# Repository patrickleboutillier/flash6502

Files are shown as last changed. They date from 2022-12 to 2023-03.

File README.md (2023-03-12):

# flash6502
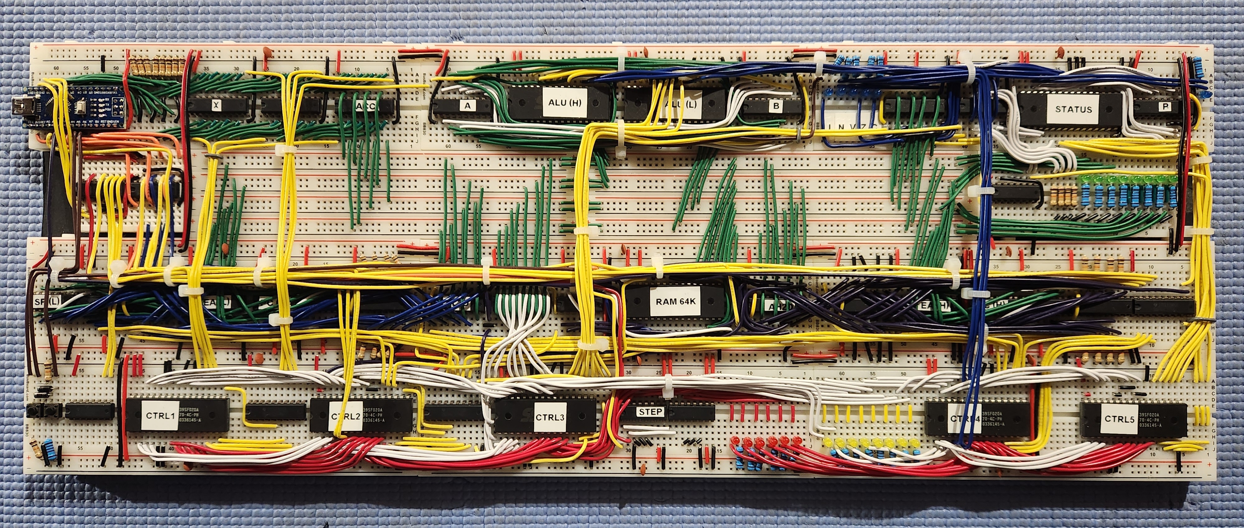
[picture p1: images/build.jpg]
Build


Trying to build a 6502-compatible CPU on breadboards, using as few chips as possible.

## Introduction
For a while I've been working on small projects that implement various "toy/fictitious" CPUs (namely the [Scott CPU](https://github.com/patrickleboutillier/jcscpu-hmc)) using discrete components, but I grew frustrated for 2 reasons:

1. Memory space is usually to small to create useful/fun programs.
2. You have to write your own assembler and tool chain.

After viewing Ben Eater's great video series on the 6502, I wondered if it might be possible to implement a 6502 CPU (not *a computer using a 6502 CPU chip*...) on breadboards using discrete components. Also, since breadboard projects tend to take up a lot of space very quickly (in squares inches I mean), I decided to try and use the least amount of chips possible, ideally under 40.

## Architecture

### Architecture Decisions
In order to achieve these goals, I made the following architecture decisions:

- It's ok if it's slower (perhaps even some orders of magnitude slower) than a real 6502.
- It's ok for the design to be assisted by a microcontroller (i.e. Arduino) for power, clocking and for some complicated parts like the reset sequence.
- It's ok if it doesn't run actual existing 6502 ROMs, but it has to run programs that I write myself using a standard 6502 assembler.
- It's ok if the actual 6502 timing is not respected.
- It's ok to use chips that did not exist at the time the 6502 was designed, namely large ROMs (which are used extensively), in order to keep the chips count low and simplify the design.

### High-Level Architecture
The system is made up of 8 sections, which I will refer to using the following names:

- **Registers**: contains the Arduino controller, as well as the X, Y and ACC registers.
- **ALU**: contains the 8-bit ALU with 16 operations, as well as the A and B registers that are connected to it.
- **Status**: contains the status (P) register, as well as the status logic implementd in a ROM chip. There is also a multiplexer to select the source for the status bits (ALU or data bus) and a buffer to control sending the status byte to the data bus.
- **Data Bus**: the 8 bit data bus.
- **Address Low**: contains the low bytes of the stack pointer (SP), the program counter (PC) and the effective address (EA) register, all connected to the "address low" bus, as well as a buffer to allow sourcing any of these from the data bus.
- **Address High**: contains the high bytes of the stack pointer (SP), the program counter (PC) and the effective address (EA) register, all connected to the "address low" bus, as well as a buffer to allow sourcing any of these (except the high byte of SP which is a constant) from the data bus.
- **RAM**: contains the instruction register (INST), the 64k RAM chip (connected to the "address low" and "address high" busses, as well as the data bus) and the memory mapping logic, as well as 2 buffers allowing to send the contents of the "address low/high" buses to the data bus.
- **Control Unit**: contains the stepping logic and 5 ROM chips that handle the 40 control signals. Each ROM chip receives the output of the step counting (6 bits), the output of the INST register (8 bits), as well as 4 other input signals that vary depending on the chip.

### Breadboard Block Diagram
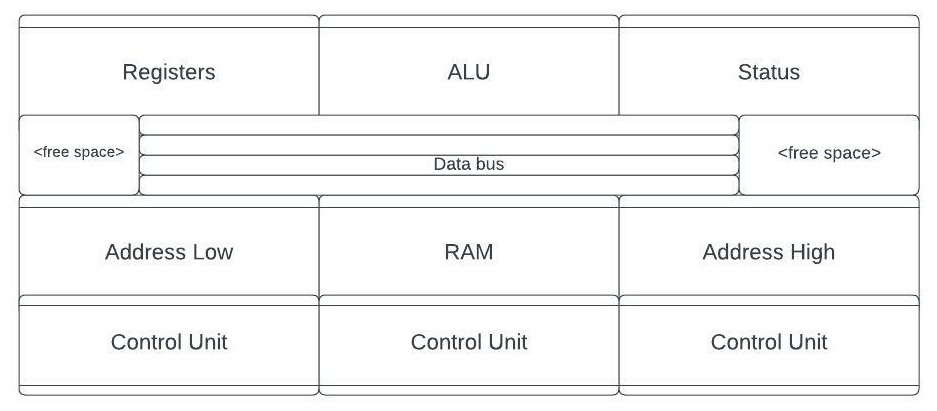
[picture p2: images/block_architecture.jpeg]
Block Diagram


## Sections
### Registers
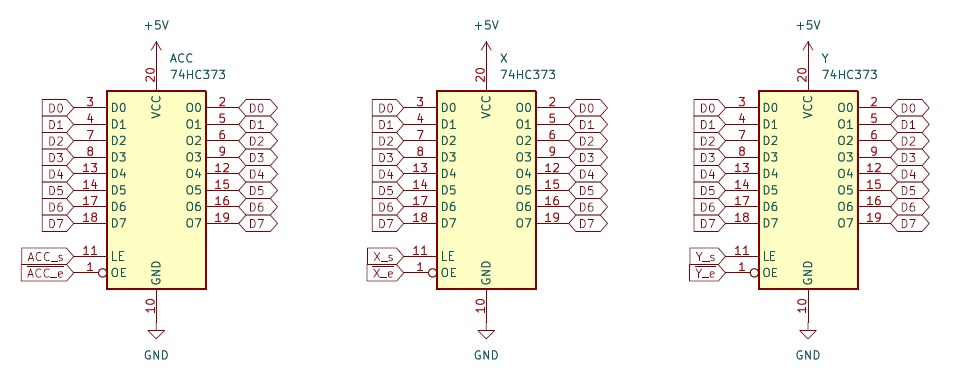
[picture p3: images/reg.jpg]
Registers


The Registers section contains 3 registers, ACC, X and Y, implemented using SN74HC373 chips. These registers are connected to the Data Bus. There are 6 control signals used to set or enable each of these 3 registers: *ACC_e*, *ACC_s*, *X_e*, *X_s*, *Y_e*, *Y_s*.

### ALU
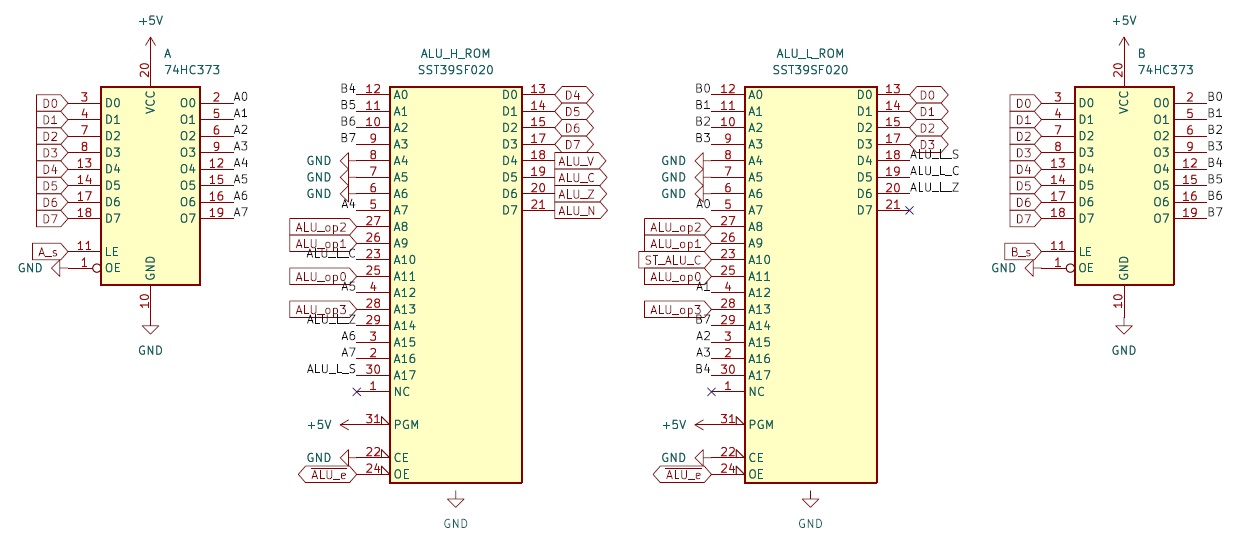
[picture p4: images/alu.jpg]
ALU


The ALU section contains 2 registers, A and B, implemented using SN74HC373 chips. These registers can be set from the Data Bus, and their outputs are fed directly into the ALU. The ALU is made up of 2 SST39SF020A Flash chips. It has 15 operations that can be selected using 4 controls bits.
The operations are defined as such:

    #define ALU_ADC  0    // For ADC instruction
    #define ALU_AND  1    // For AND instruction
    #define ALU_BIT  2    // For BIT instruction
    #define ALU_CMP  3    // For CMP instruction
    #define ALU_DEC  4    // For DEC instruction
    #define ALU_EOR  5    // For EOR instruction
    #define ALU_INC  6    // For ADC instruction
    #define ALU_LSR  7    // For LSR instruction
    #define ALU_ORA  8    // For ORA instruction
    #define ALU_ROL  9    // For ROL instruction
    #define ALU_ROR  10   // For ROR instruction
    #define ALU_SBC  11   // For SBC instruction
    #define ALU_PASS 12   // Passes through the contents of the B register
    #define ALU_ADD  13   // ADD w/o carry. Used mostly in address calculations
    #define ALU_SXT  14   // Sign extention, used in relative address calculation

Here are the details of each of the pins for the 2 Flash chips, ALU Low and ALU High:
#### ALU Low
- A16, A15, A12, A7: The low nibble of the A register.
- A3, A2, A1, A0: The low nibble of the B register.
- A13, A8, A9, A11: The ALU operation (see above).
- A10: The "ALU carry" output of the Status section.
- A17: Bit 4 of the B register. Used, for example, during the "shift right" operations.
- A14: Bit 7 of the B register. Used during the "sign extend" operation. 
- DQ3, DQ2, DQ1, DQ0: The low nibble of the result of the operation (these pins are connected to the Data Bus).
- DQ6: The "zero" output of the operation.
- DQ5: The "carry" output of the operation.
- DQ4: The "shift" output of the operation.
- OE#: Connected to the *ALU_e* control signal used to enable the result onto the Data Bus.

#### ALU High
- A16, A15, A12, A7: The high nibble of the A register.
- A3, A2, A1, A0: The high nibble of the B register.
- A13, A8, A9, A11: The ALU operation (see above).
- A10: The "carry" output from ALU Low.
- A17: The "shift" output fron ALU Low.
- A14: The "zero" output fron ALU Low.
- DQ3, DQ2, DQ1, DQ0: The high nobble of the result of the operation (these pins are connected to the Data Bus).
- DQ7: The N output flag of the ALU.
- DQ6: The Z output flag of the ALU.
- DQ5: The C output flag of the ALU.
- DQ4: The V output flag of the ALU.
- OE#: Connected to the *ALU_e* control signal used to enable the result onto the Data Bus.

#### Control signals
The control signals for the ALU section are *ALU[3-0]*, *ALU_e*, *A_s* and *B_s*.

### Status
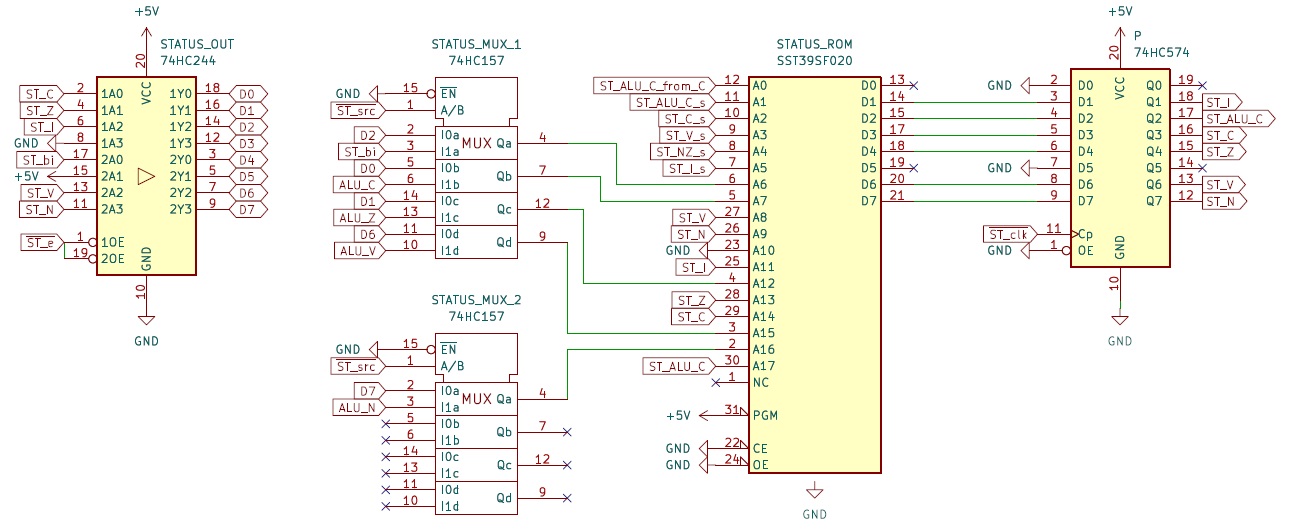
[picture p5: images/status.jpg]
Status

The Status section is made up of the P register, which stores the current values for the Status flags, as well a custom flag (ALU_C) to store the carry used for the ALU carry-in signal, which may be different from the Status carry (C) flag.

The Status ROM is the brains of the Status module. It receives as input:
- The outputs of the P register (the "current" Status flag values)
- The "new" Status flag inputs, that come either from the ALU or from the Data Bus
  - 2 SN74HC157 MUX chips are used to feed these inputs to the Status ROM 
- Control signals that indicate which Status flags are to be set

Finally the Status module also contains a SN74HC244 chip that controls the sending of the Status flags to the Data Bus when required.

#### Control signals
The control signals for the Status section are *ST_e*, *ST_bi*, *ST_src*, *ST_NZ_s*, *ST_C_s*, *ST_V_s*, *ST_I_s*, *ST_ALU_C_s*, *ST_ALU_C_from_C*.

### Data Bus
The Data Bus is really just a combination of 4 breadboard power rails, along with some LEDs to help with debugging.
### Address Low
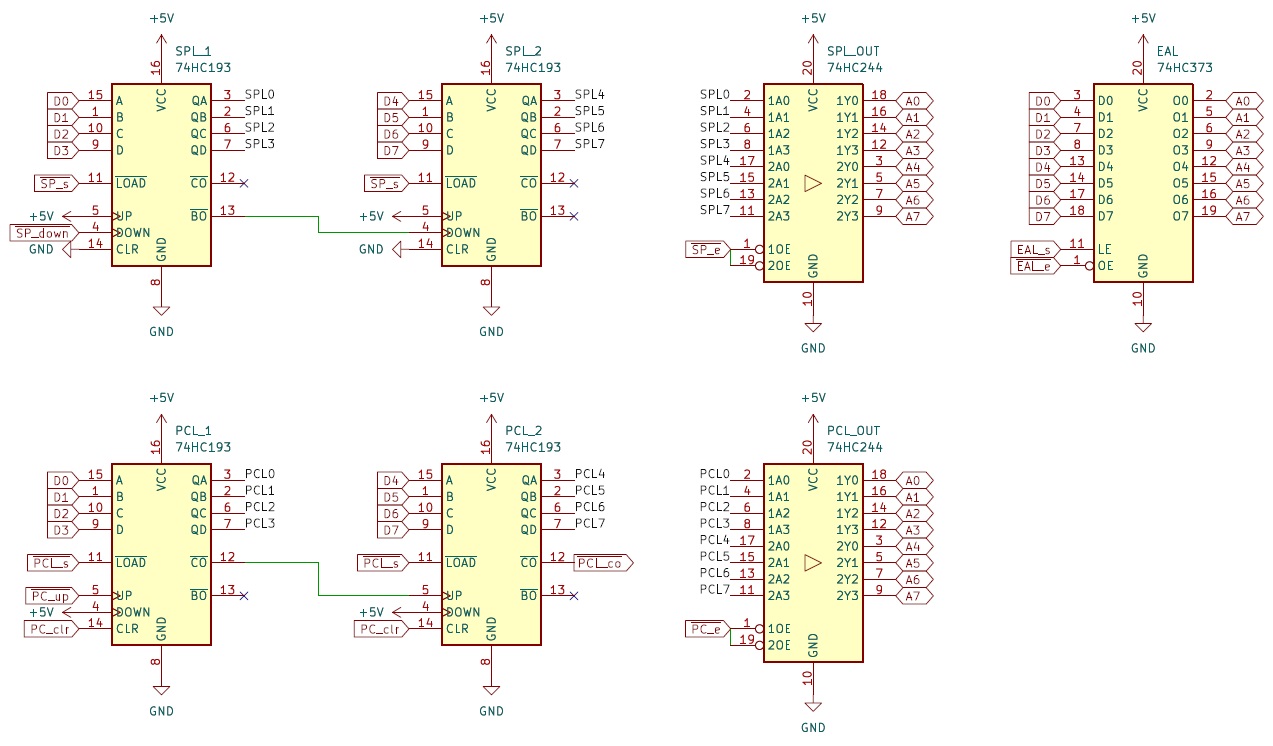
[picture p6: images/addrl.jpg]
Address Low

TODO: Description
### Address High
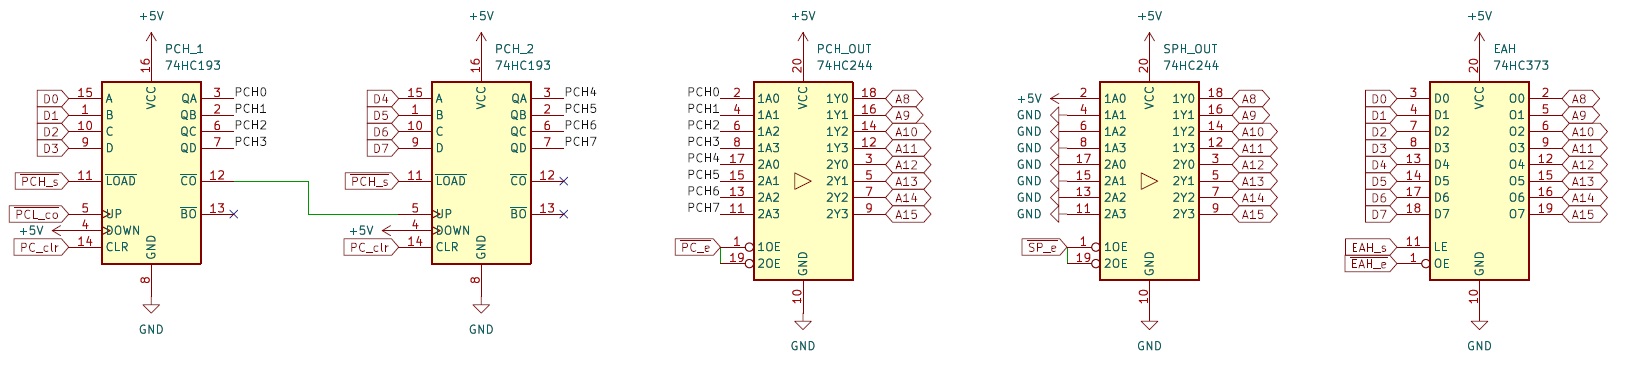
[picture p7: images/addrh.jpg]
Address High

TODO: Description
### RAM
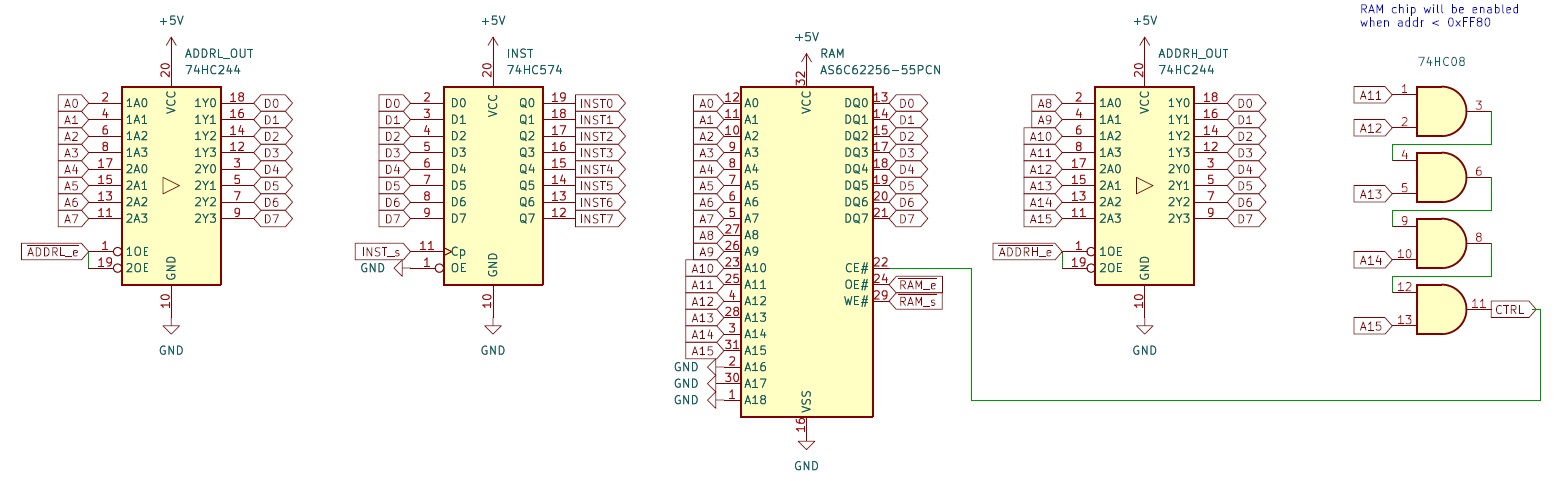
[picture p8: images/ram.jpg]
RAM

TODO: Description
### Control Unit
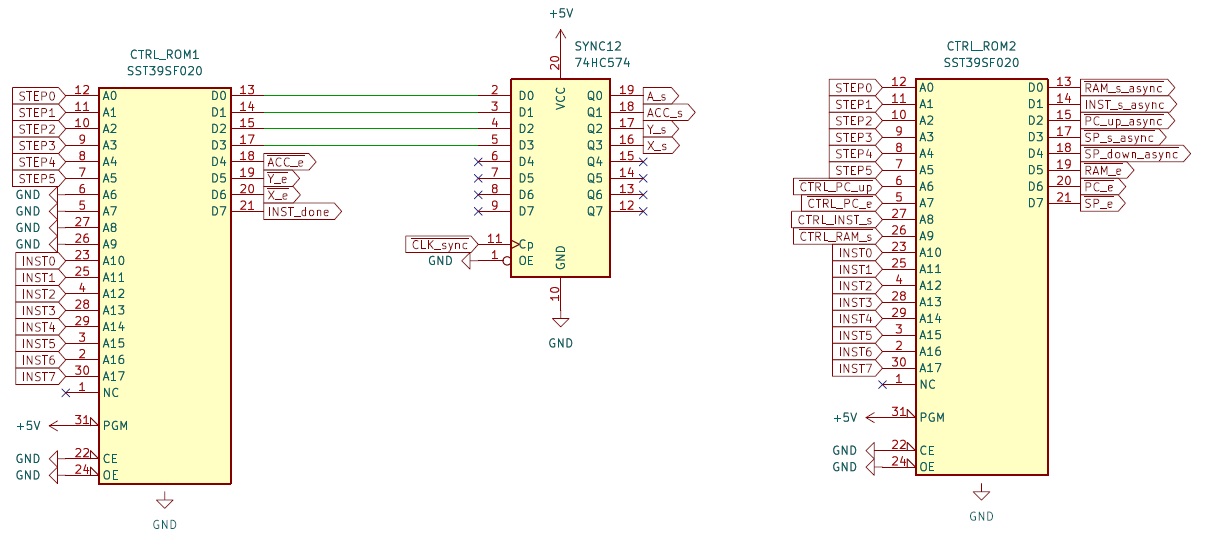
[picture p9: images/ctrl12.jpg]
CU12

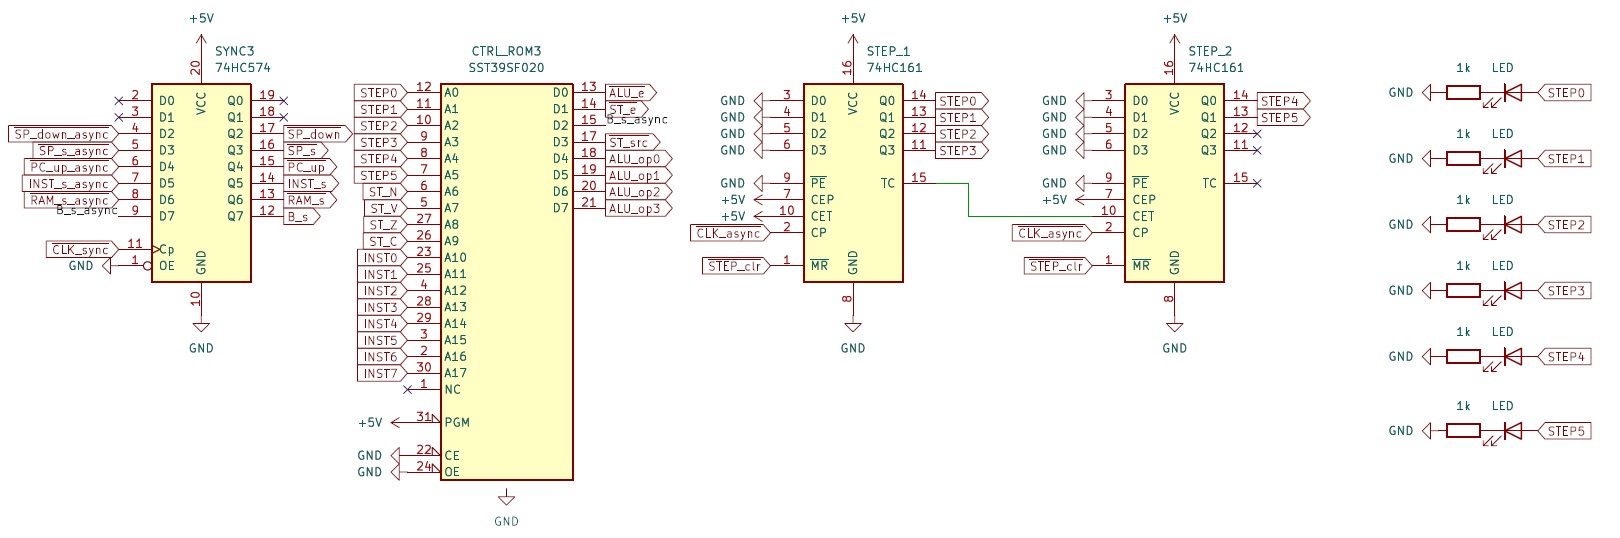
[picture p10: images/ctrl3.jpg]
CU3

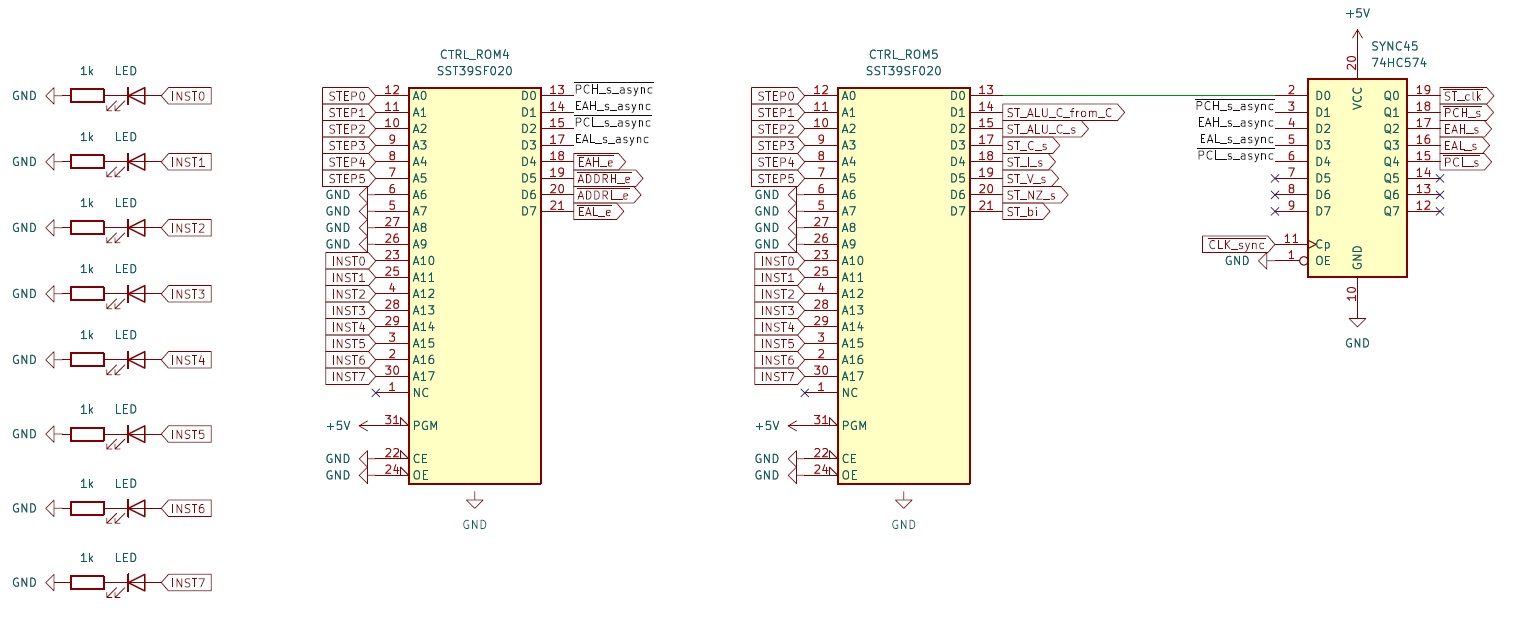
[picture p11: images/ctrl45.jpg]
CU45

TODO: Description
### Arduino Controller
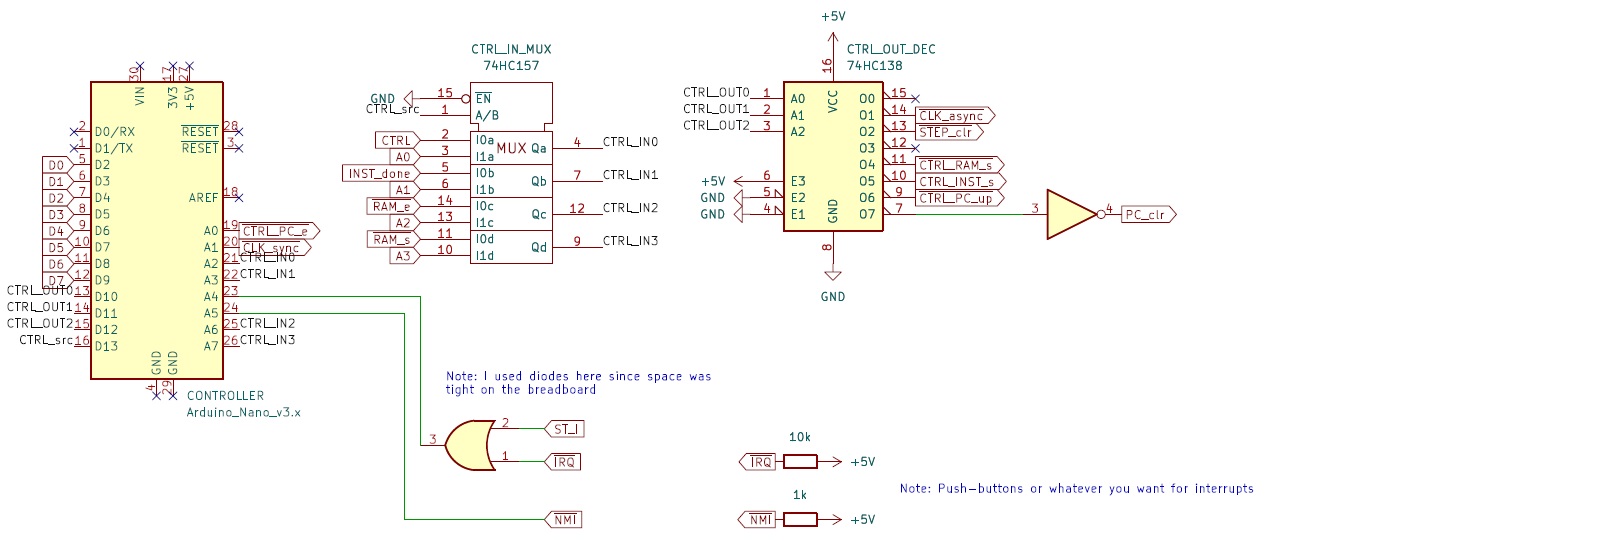
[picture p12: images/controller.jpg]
Controller

TODO: Description

## Schematic
You can find the complete KiCAD Schematic here: [KiCAD Schematic](./docs/kicad/flash6502/)

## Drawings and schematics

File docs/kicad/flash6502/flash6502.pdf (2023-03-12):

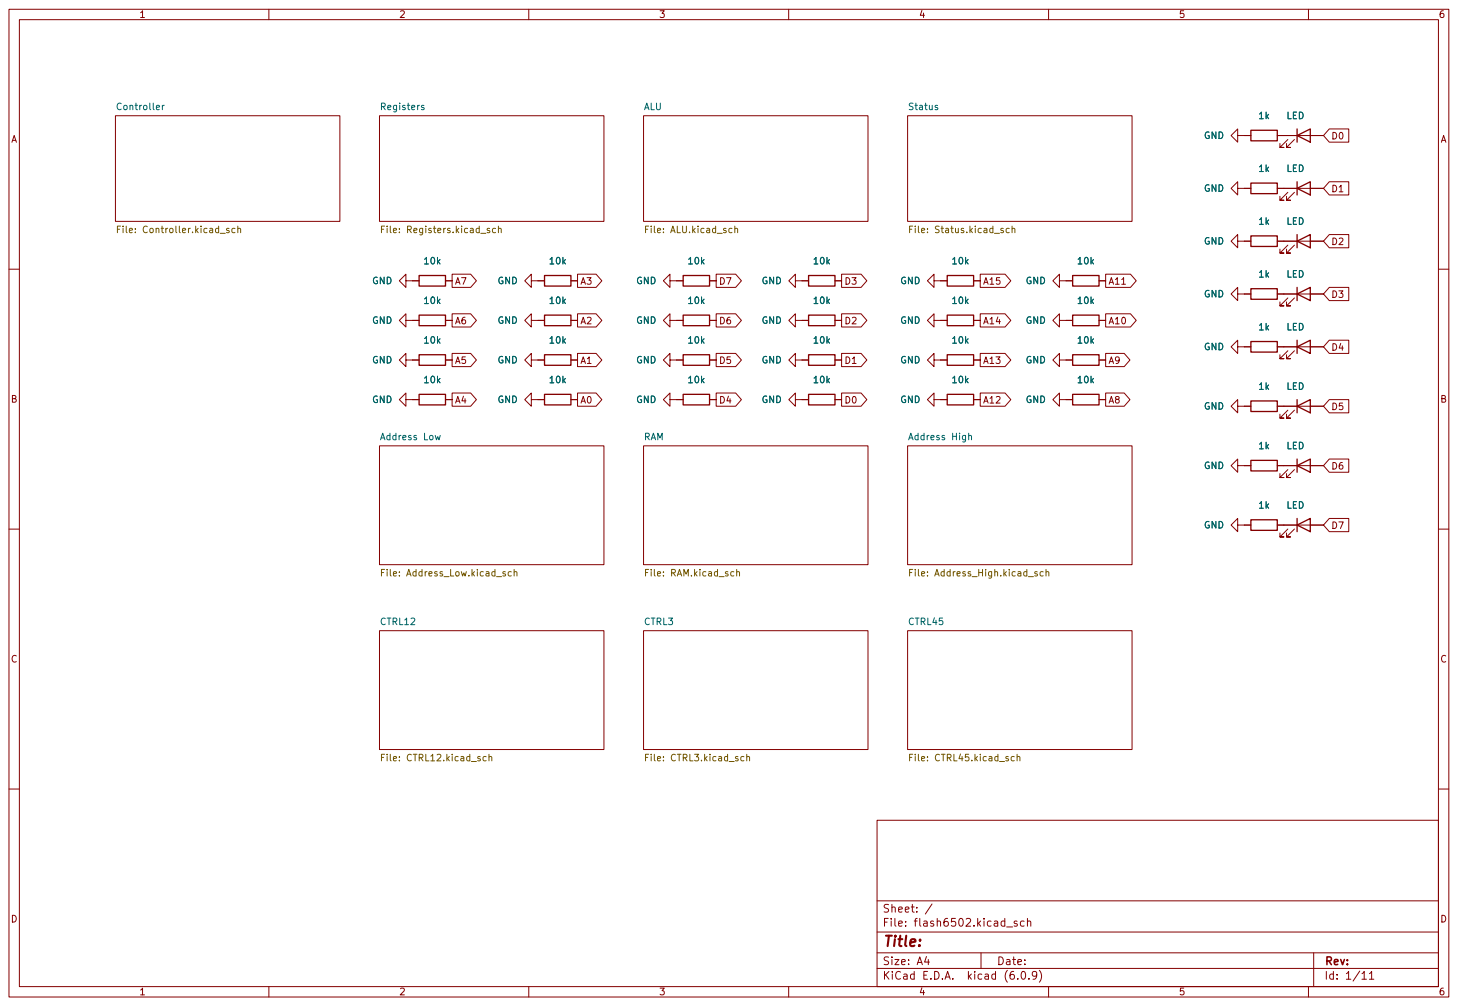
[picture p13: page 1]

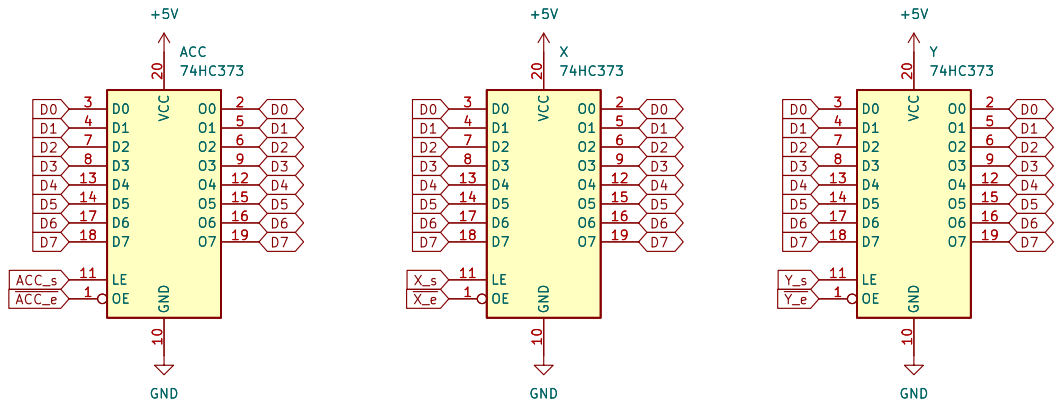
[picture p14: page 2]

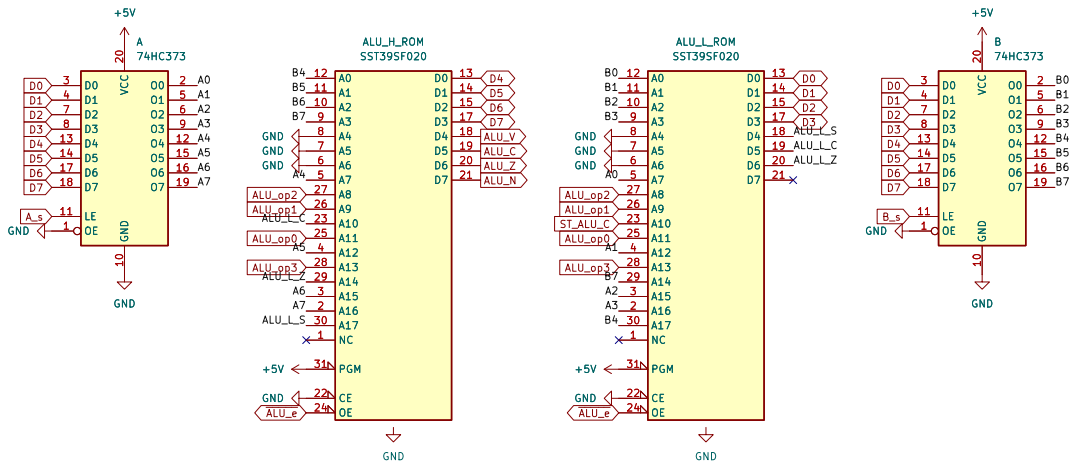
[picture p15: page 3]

File: ALU.kicad_sch Sheet: /ALU/
Id: 3/11 Title:

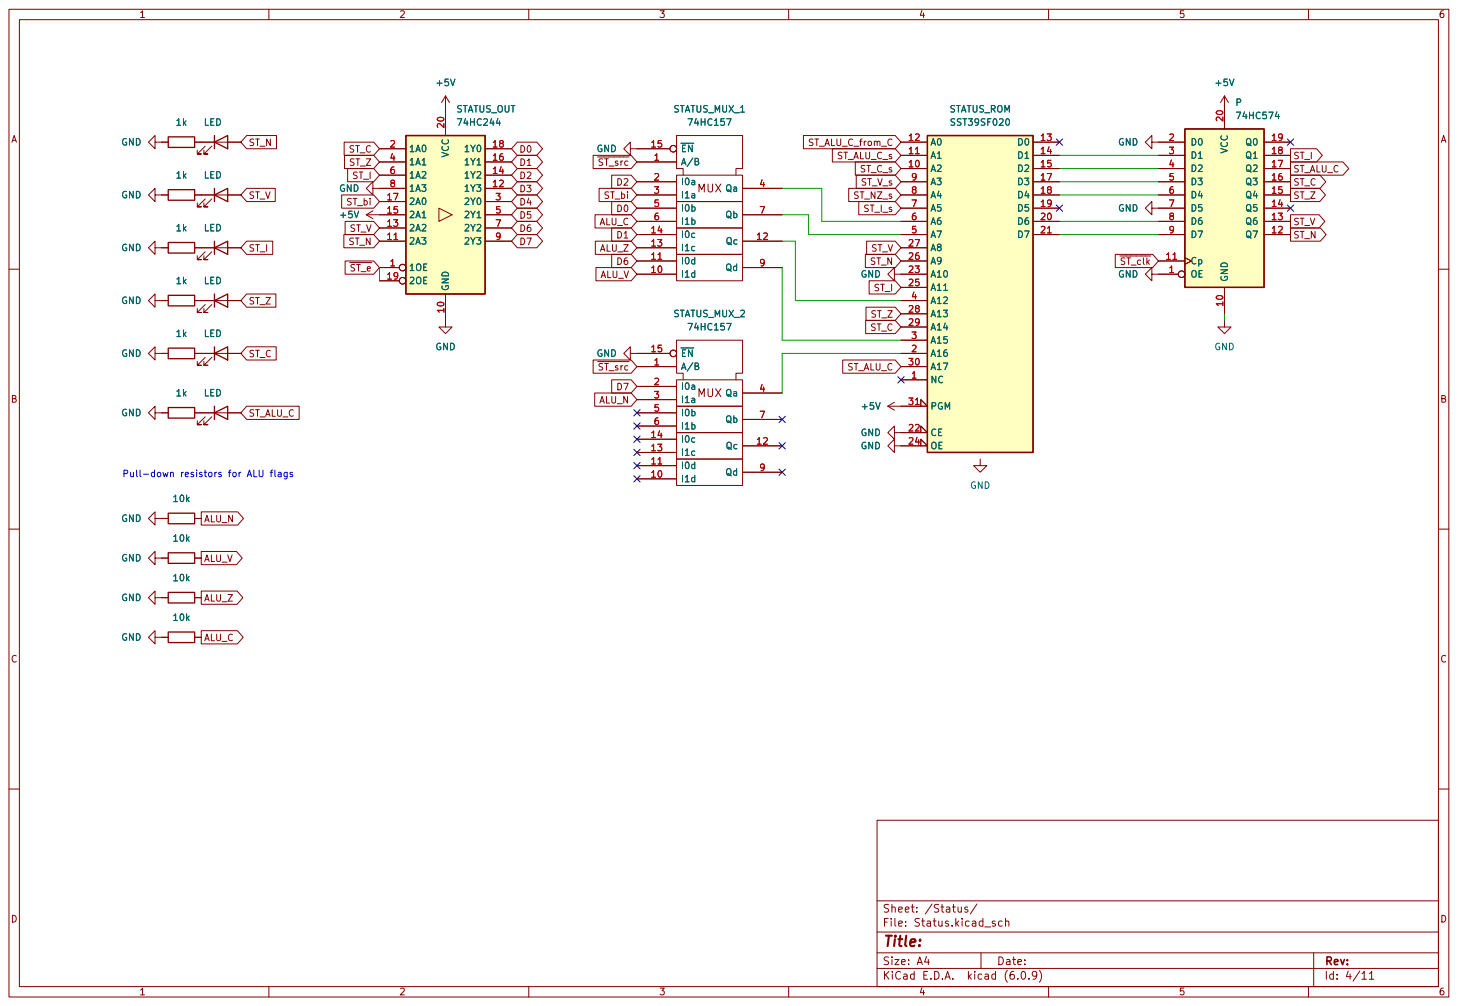
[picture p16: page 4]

File: Status.kicad_sch Sheet: /Status/
Id: 4/11 Title:

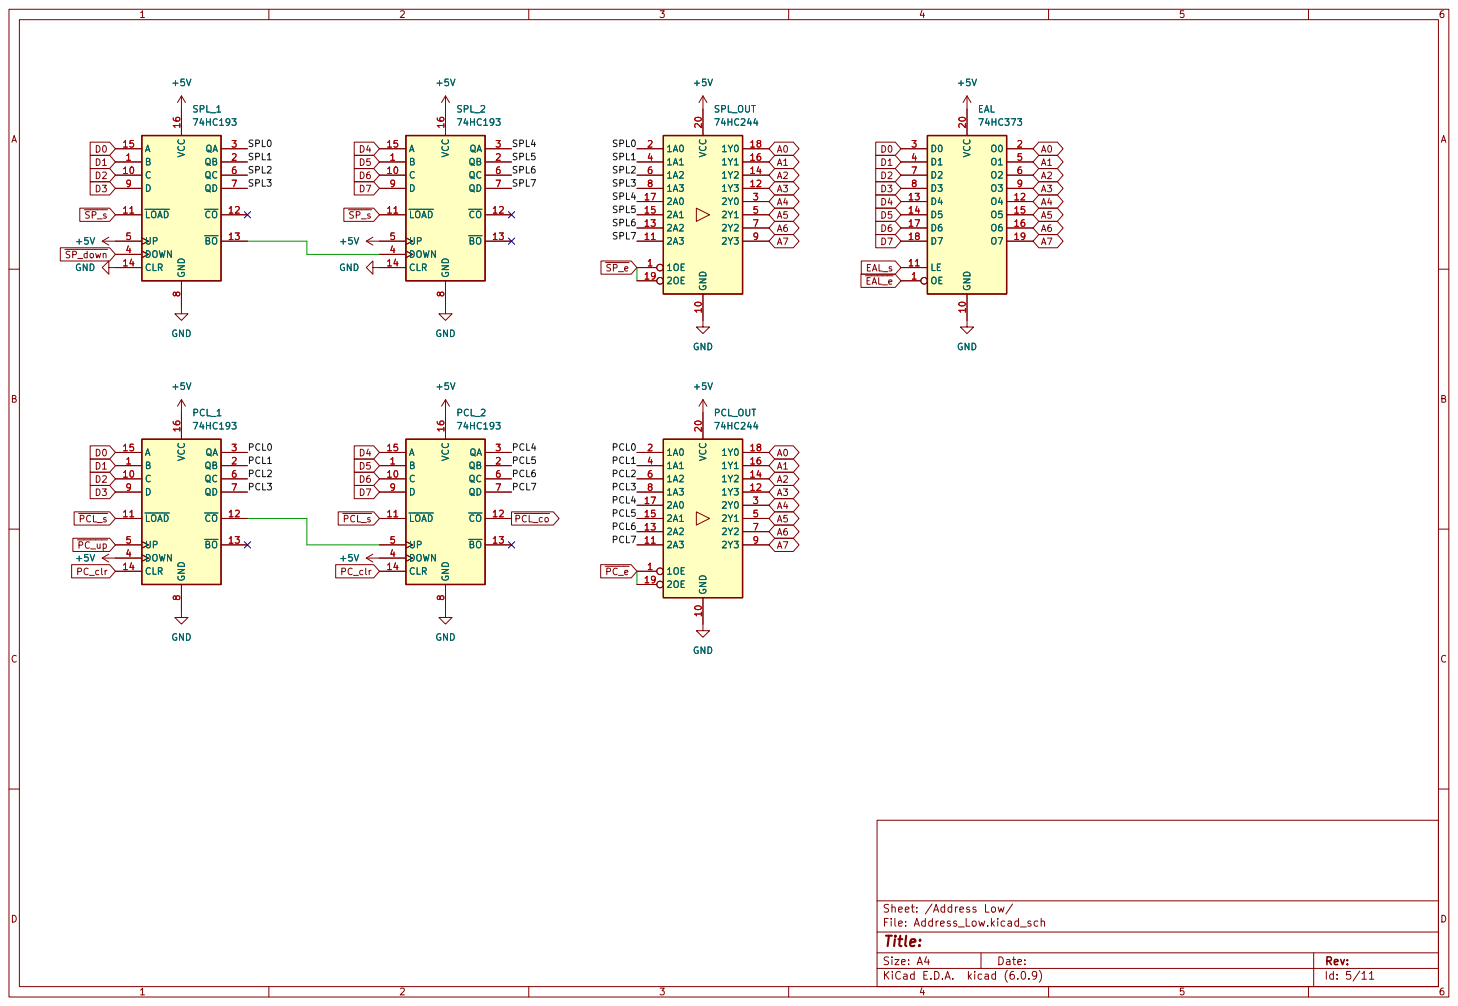
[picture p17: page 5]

File: Address_Low.kicad_sch Sheet: /Address Low/
Id: 5/11 Title:

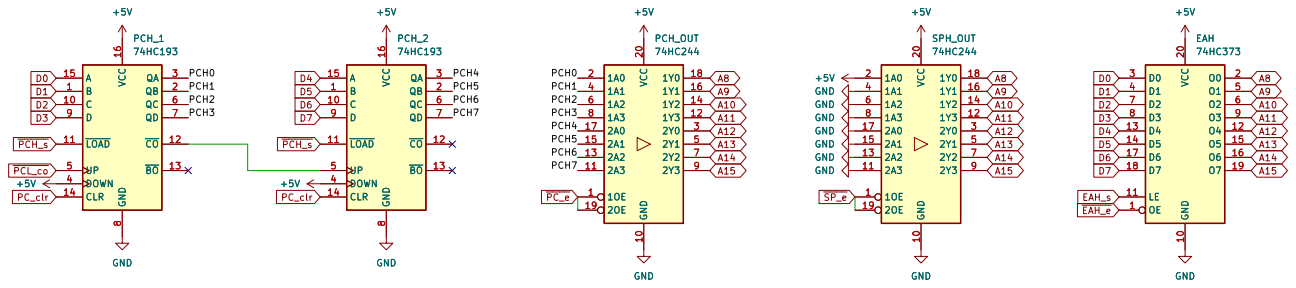
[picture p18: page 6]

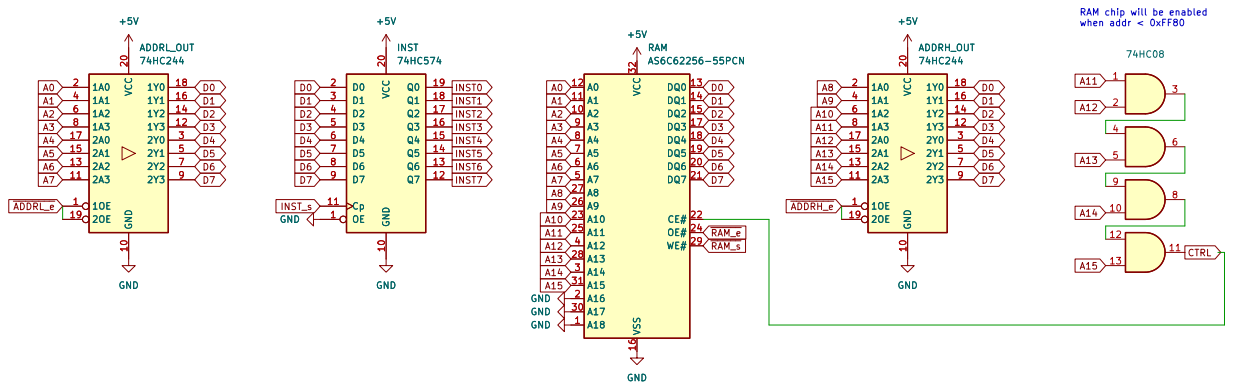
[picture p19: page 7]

File: RAM.kicad_sch Sheet: /RAM/
Id: 7/11 Title:

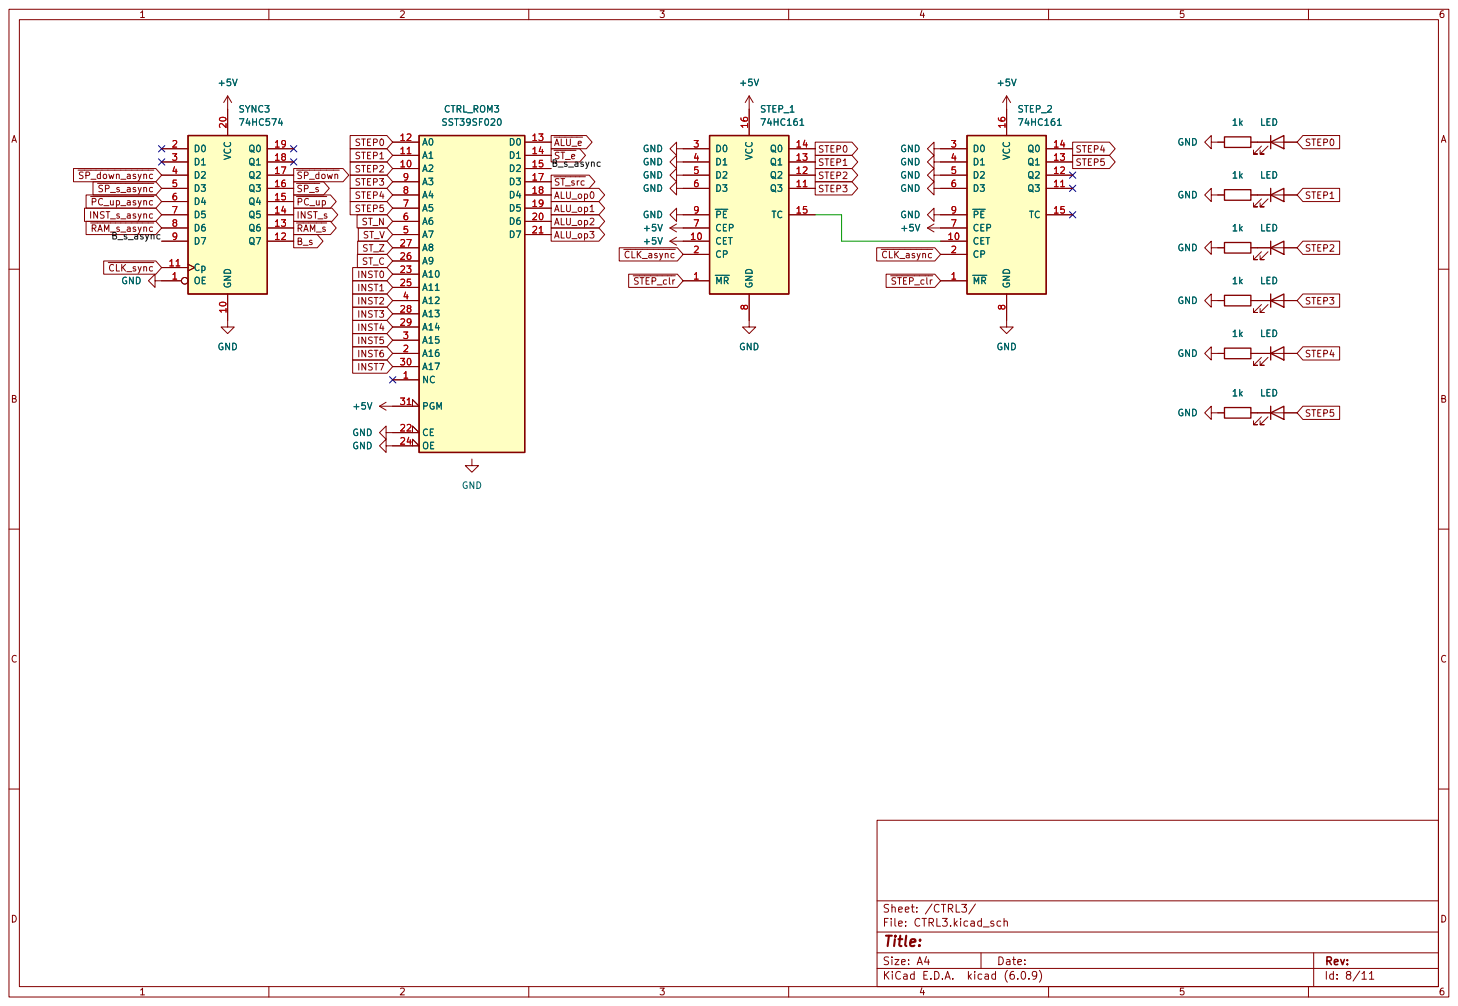
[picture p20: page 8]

+5V GND GND GND GND

8 ~{PE} 9 GND GND GND GND

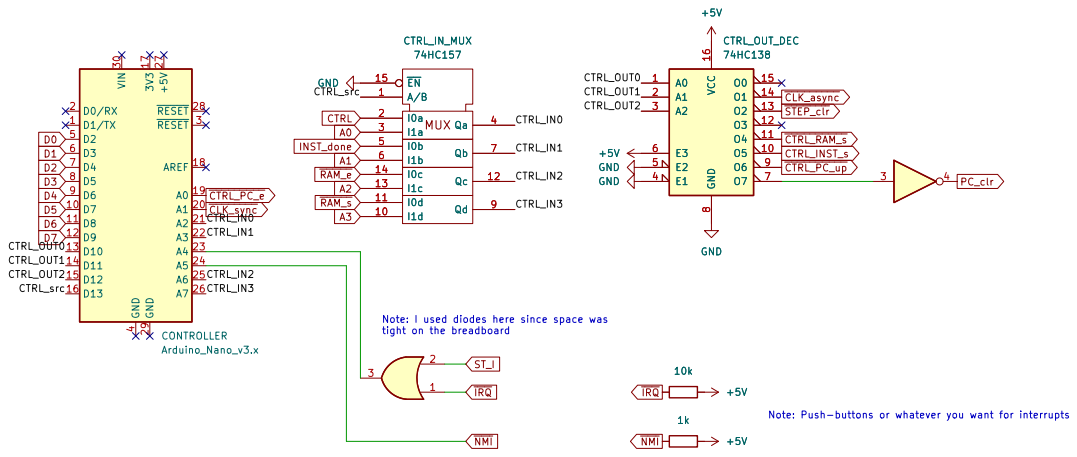
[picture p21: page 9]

Note: Push-buttons or whatever you want for interrupts +5V GND GND

tight on the breadboard

File: Controller.kicad_sch Sheet: /Controller/
Id: 9/11 Title:

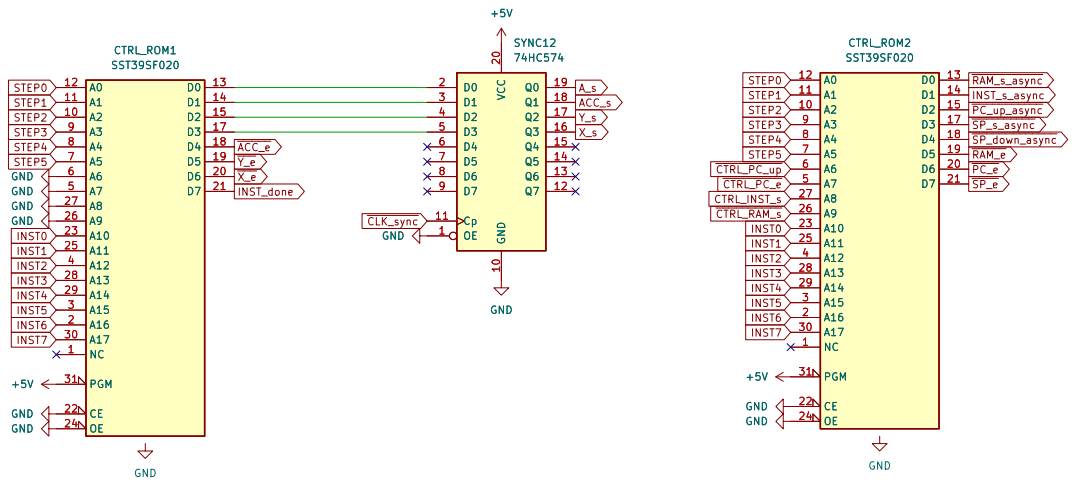
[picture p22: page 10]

+5V GND GND GND GND

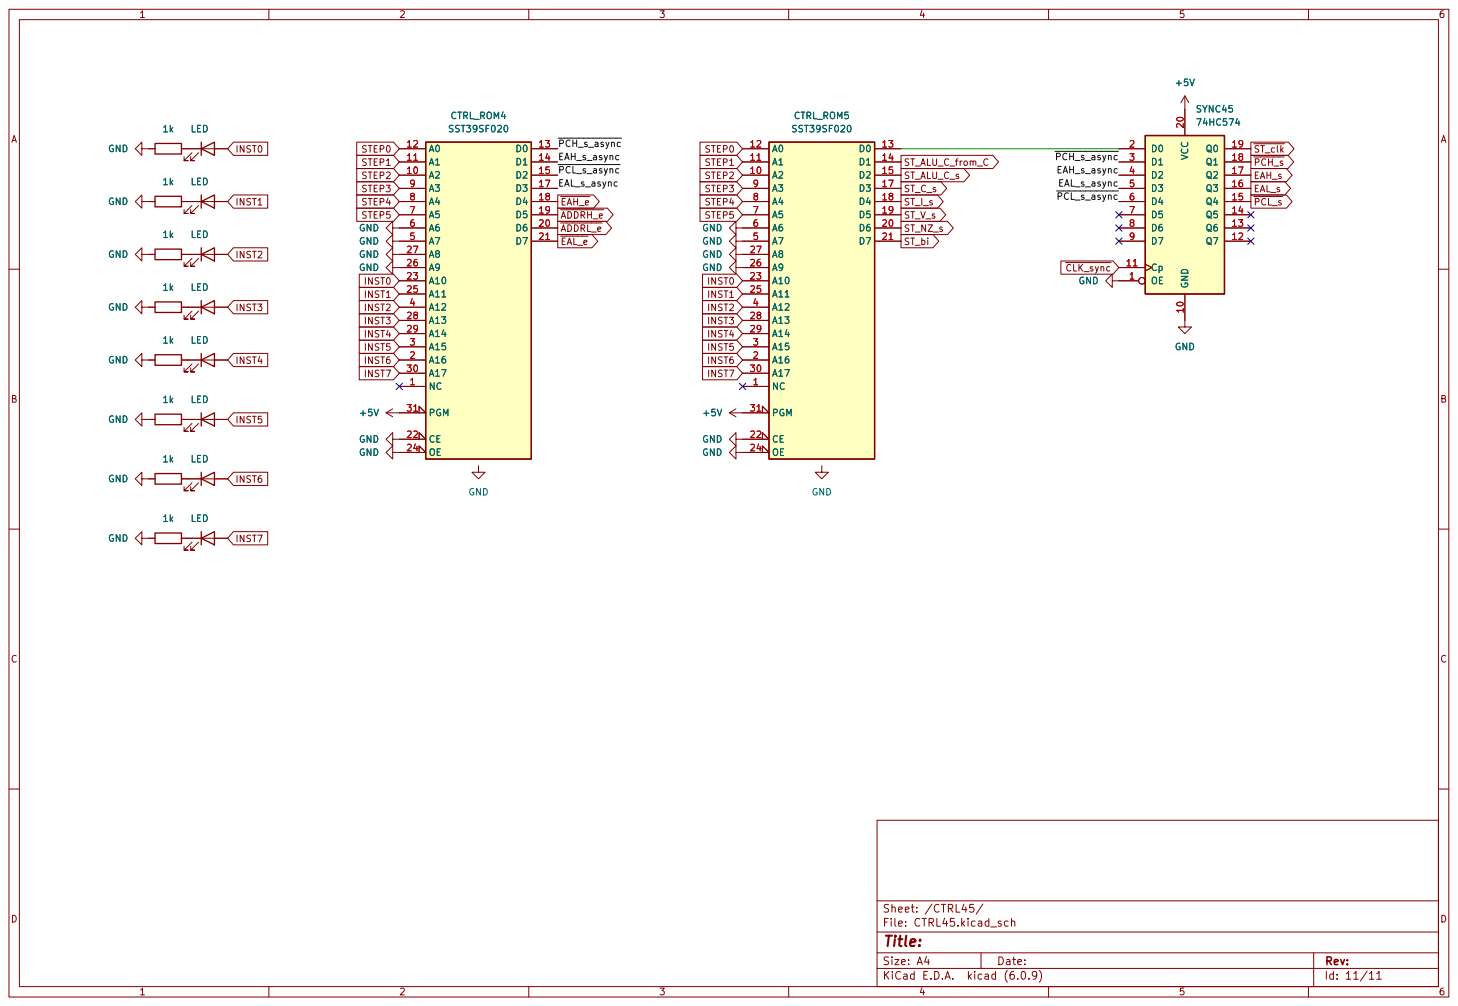
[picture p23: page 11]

+5V GND GND GND GND

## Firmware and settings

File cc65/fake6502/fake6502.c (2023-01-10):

/* Fake6502 CPU emulator core v1.1 *******************
 * (c)2011 Mike Chambers (miker00lz@gmail.com)       *
 *****************************************************
 * v1.1 - Small bugfix in BIT opcode, but it was the *
 *        difference between a few games in my NES   *
 *        emulator working and being broken!         *
 *        I went through the rest carefully again    *
 *        after fixing it just to make sure I didn't *
 *        have any other typos! (Dec. 17, 2011)      *
 *                                                   *
 * v1.0 - First release (Nov. 24, 2011)              *
 *****************************************************
 * LICENSE: This source code is released into the    *
 * public domain, but if you use it please do give   *
 * credit. I put a lot of effort into writing this!  *
 *                                                   *
 *****************************************************
 * Fake6502 is a MOS Technology 6502 CPU emulation   *
 * engine in C. It was written as part of a Nintendo *
 * Entertainment System emulator I've been writing.  *
 *                                                   *
 * A couple important things to know about are two   *
 * defines in the code. One is "UNDOCUMENTED" which, *
 * when defined, allows Fake6502 to compile with     *
 * full support for the more predictable             *
 * undocumented instructions of the 6502. If it is   *
 * undefined, undocumented opcodes just act as NOPs. *
 *                                                   *
 * The other define is "NES_CPU", which causes the   *
 * code to compile without support for binary-coded  *
 * decimal (BCD) support for the ADC and SBC         *
 * opcodes. The Ricoh 2A03 CPU in the NES does not   *
 * support BCD, but is otherwise identical to the    *
 * standard MOS 6502. (Note that this define is      *
 * enabled in this file if you haven't changed it    *
 * yourself. If you're not emulating a NES, you      *
 * should comment it out.)                           *
 *                                                   *
 * If you do discover an error in timing accuracy,   *
 * or operation in general please e-mail me at the   *
 * address above so that I can fix it. Thank you!    *
 *                                                   *
 *****************************************************
 * Usage:                                            *
 *                                                   *
 * Fake6502 requires you to provide two external     *
 * functions:                                        *
 *                                                   *
 * uint8_t read6502(uint16_t address)                *
 * void write6502(uint16_t address, uint8_t value)   *
 *                                                   *
 * You may optionally pass Fake6502 the pointer to a *
 * function which you want to be called after every  *
 * emulated instruction. This function should be a   *
 * void with no parameters expected to be passed to  *
 * it.                                               *
 *                                                   *
 * This can be very useful. For example, in a NES    *
 * emulator, you check the number of clock ticks     *
 * that have passed so you can know when to handle   *
 * APU events.                                       *
 *                                                   *
 * To pass Fake6502 this pointer, use the            *
 * hookexternal(void *funcptr) function provided.    *
 *                                                   *
 * To disable the hook later, pass NULL to it.       *
 *****************************************************
 * Useful functions in this emulator:                *
 *                                                   *
 * void reset6502()                                  *
 *   - Call this once before you begin execution.    *
 *                                                   *
 * void exec6502(uint32_t tickcount)                 *
 *   - Execute 6502 code up to the next specified    *
 *     count of clock ticks.                         *
 *                                                   *
 * void step6502()                                   *
 *   - Execute a single instrution.                  *
 *                                                   *
 * void irq6502()                                    *
 *   - Trigger a hardware IRQ in the 6502 core.      *
 *                                                   *
 * void nmi6502()                                    *
 *   - Trigger an NMI in the 6502 core.              *
 *                                                   *
 * void hookexternal(void *funcptr)                  *
 *   - Pass a pointer to a void function taking no   *
 *     parameters. This will cause Fake6502 to call  *
 *     that function once after each emulated        *
 *     instruction.                                  *
 *                                                   *
 *****************************************************
 * Useful variables in this emulator:                *
 *                                                   *
 * uint32_t clockticks6502                           *
 *   - A running total of the emulated cycle count.  *
 *                                                   *
 * uint32_t instructions                             *
 *   - A running total of the total emulated         *
 *     instruction count. This is not related to     *
 *     clock cycle timing.                           *
 *                                                   *
 *****************************************************/

#include <stdio.h>
#include <stdint.h>
#include <stdlib.h>
#include <unistd.h>
#include <fcntl.h>

//6502 defines
#define UNDOCUMENTED //when this is defined, undocumented opcodes are handled.
                     //otherwise, they're simply treated as NOPs.

#define NES_CPU      //when this is defined, the binary-coded decimal (BCD)
                     //status flag is not honored by ADC and SBC. the 2A03
                     //CPU in the Nintendo Entertainment System does not
                     //support BCD operation.

#define FLAG_CARRY     0x01
#define FLAG_ZERO      0x02
#define FLAG_INTERRUPT 0x04
#define FLAG_DECIMAL   0x08
#define FLAG_BREAK     0x10
#define FLAG_CONSTANT  0x20
#define FLAG_OVERFLOW  0x40
#define FLAG_SIGN      0x80

#define BASE_STACK     0x100

#define saveaccum(n) a = (uint8_t)((n) & 0x00FF)


//flag modifier macros
#define setcarry() status |= FLAG_CARRY
#define clearcarry() status &= (~FLAG_CARRY)
#define setzero() status |= FLAG_ZERO
#define clearzero() status &= (~FLAG_ZERO)
#define setinterrupt() status |= FLAG_INTERRUPT
#define clearinterrupt() status &= (~FLAG_INTERRUPT)
#define setdecimal() status |= FLAG_DECIMAL
#define cleardecimal() status &= (~FLAG_DECIMAL)
#define setoverflow() status |= FLAG_OVERFLOW
#define clearoverflow() status &= (~FLAG_OVERFLOW)
#define setsign() status |= FLAG_SIGN
#define clearsign() status &= (~FLAG_SIGN)


//flag calculation macros
#define zerocalc(n) {\
    if ((n) & 0x00FF) clearzero();\
        else setzero();\
}

#define signcalc(n) {\
    if ((n) & 0x0080) setsign();\
        else clearsign();\
}

#define carrycalc(n) {\
    if ((n) & 0xFF00) setcarry();\
        else clearcarry();\
}

#define overflowcalc(n, m, o) { /* n = result, m = accumulator, o = memory */ \
    if (((n) ^ (uint16_t)(m)) & ((n) ^ (o)) & 0x0080) setoverflow();\
        else clearoverflow();\
}


//6502 CPU registers
uint16_t pc;
uint8_t sp, a, x, y, status;


//helper variables
uint32_t instructions = 0; //keep track of total instructions executed
uint32_t clockticks6502 = 0, clockgoal6502 = 0;
uint16_t oldpc, ea, reladdr, value, result;
uint8_t opcode, oldstatus;

uint8_t MEM[0x10000] ;
uint8_t read6502(uint16_t address){
    return MEM[address] ;
}

void write6502(uint16_t address, uint8_t value){
    MEM[address] = value ;
    if (address == 0xFFF1){
        printf("%c", value) ;
    }
    else if (address == 0xFFF9){
        printf("HALTED!\n") ;
        exit(0) ;
    }
}

//a few general functions used by various other functions
void push16(uint16_t pushval) {
    write6502(BASE_STACK + sp, (pushval >> 8) & 0xFF);
    write6502(BASE_STACK + ((sp - 1) & 0xFF), pushval & 0xFF);
    sp -= 2;
}

void push8(uint8_t pushval) {
    write6502(BASE_STACK + sp--, pushval);
}

uint16_t pull16() {
    uint16_t temp16;
    temp16 = read6502(BASE_STACK + ((sp + 1) & 0xFF)) | ((uint16_t)read6502(BASE_STACK + ((sp + 2) & 0xFF)) << 8);
    sp += 2;
    return(temp16);
}

uint8_t pull8() {
    return (read6502(BASE_STACK + ++sp));
}

void reset6502() {
    pc = (uint16_t)read6502(0xFFFC) | ((uint16_t)read6502(0xFFFD) << 8);
    a = 0;
    x = 0;
    y = 0;
    sp = 0xFD;
    status |= (FLAG_CONSTANT | FLAG_INTERRUPT) ;
}


static void (*addrtable[256])();
static void (*optable[256])();
uint8_t penaltyop, penaltyaddr;

//addressing mode functions, calculates effective addresses
static void imp() { //implied
}

static void acc() { //accumulator
}

static void imm() { //immediate
    ea = pc++;
}

static void zp() { //zero-page
    ea = (uint16_t)read6502((uint16_t)pc++);
}

static void zpx() { //zero-page,X
    ea = ((uint16_t)read6502((uint16_t)pc++) + (uint16_t)x) & 0xFF; //zero-page wraparound
}

static void zpy() { //zero-page,Y
    ea = ((uint16_t)read6502((uint16_t)pc++) + (uint16_t)y) & 0xFF; //zero-page wraparound
}

static void rel() { //relative for branch ops (8-bit immediate value, sign-extended)
    reladdr = (uint16_t)read6502(pc++);
    if (reladdr & 0x80) reladdr |= 0xFF00;
    ea = pc + reladdr ; 
}

static void abso() { //absolute
    ea = (uint16_t)read6502(pc) | ((uint16_t)read6502(pc+1) << 8);
    pc += 2;
}

static void absx() { //absolute,X
    uint16_t startpage;
    ea = ((uint16_t)read6502(pc) | ((uint16_t)read6502(pc+1) << 8));
    startpage = ea & 0xFF00;
    ea += (uint16_t)x;

    if (startpage != (ea & 0xFF00)) { //one cycle penlty for page-crossing on some opcodes
        penaltyaddr = 1;
    }

    pc += 2;
}

static void absy() { //absolute,Y
    uint16_t startpage;
    ea = ((uint16_t)read6502(pc) | ((uint16_t)read6502(pc+1) << 8));
    startpage = ea & 0xFF00;
    ea += (uint16_t)y;

    if (startpage != (ea & 0xFF00)) { //one cycle penlty for page-crossing on some opcodes
        penaltyaddr = 1;
    }

    pc += 2;
}

static void ind() { //indirect
    uint16_t eahelp, eahelp2;
    eahelp = (uint16_t)read6502(pc) | (uint16_t)((uint16_t)read6502(pc+1) << 8);
    eahelp2 = (eahelp & 0xFF00) | ((eahelp + 1) & 0x00FF); //replicate 6502 page-boundary wraparound bug
    ea = (uint16_t)read6502(eahelp) | ((uint16_t)read6502(eahelp2) << 8);
    pc += 2;
}

static void indx() { // (indirect,X)
    uint16_t eahelp;
    eahelp = (uint16_t)(((uint16_t)read6502(pc++) + (uint16_t)x) & 0xFF); //zero-page wraparound for table pointer
    ea = (uint16_t)read6502(eahelp & 0x00FF) | ((uint16_t)read6502((eahelp+1) & 0x00FF) << 8);
}

static void indy() { // (indirect),Y
    uint16_t eahelp, eahelp2, startpage;
    eahelp = (uint16_t)read6502(pc++);
    eahelp2 = (eahelp & 0xFF00) | ((eahelp + 1) & 0x00FF); //zero-page wraparound
    ea = (uint16_t)read6502(eahelp) | ((uint16_t)read6502(eahelp2) << 8);
    startpage = ea & 0xFF00;
    ea += (uint16_t)y;

    if (startpage != (ea & 0xFF00)) { //one cycle penlty for page-crossing on some opcodes
        penaltyaddr = 1;
    }
}

static uint16_t getvalue() {
    if (addrtable[opcode] == acc) return((uint16_t)a);
        else return((uint16_t)read6502(ea));
}

static uint16_t getvalue16() {
    return((uint16_t)read6502(ea) | ((uint16_t)read6502(ea+1) << 8));
}

static void putvalue(uint16_t saveval) {
    if (addrtable[opcode] == acc) a = (uint8_t)(saveval & 0x00FF);
        else write6502(ea, (saveval & 0x00FF));
}


//instruction handler functions
static void adc() {
    penaltyop = 1;
    value = getvalue();
    result = (uint16_t)a + value + (uint16_t)(status & FLAG_CARRY);
   
    carrycalc(result);
    zerocalc(result);
    overflowcalc(result, a, value);
    signcalc(result);
    
    #ifndef NES_CPU
    if (status & FLAG_DECIMAL) {
        clearcarry();
        
        if ((a & 0x0F) > 0x09) {
            a += 0x06;
        }
        if ((a & 0xF0) > 0x90) {
            a += 0x60;
            setcarry();
        }
        
        clockticks6502++;
    }
    #endif
   
    saveaccum(result);
}

static void and() {
    penaltyop = 1;
    value = getvalue();
    result = (uint16_t)a & value;
   
    zerocalc(result);
    signcalc(result);
   
    saveaccum(result);
}

static void asl() {
    value = getvalue();
    result = value << 1;

    carrycalc(result);
    zerocalc(result);
    signcalc(result);
   
    putvalue(result);
}

static void bcc() {
    if ((status & FLAG_CARRY) == 0) {
        oldpc = pc;
        pc += reladdr;
        if ((oldpc & 0xFF00) != (pc & 0xFF00)) clockticks6502 += 2; //check if jump crossed a page boundary
            else clockticks6502++;
    }
}

static void bcs() {
    if ((status & FLAG_CARRY) == FLAG_CARRY) {
        oldpc = pc;
        pc += reladdr;
        if ((oldpc & 0xFF00) != (pc & 0xFF00)) clockticks6502 += 2; //check if jump crossed a page boundary
            else clockticks6502++;
    }
}

static void beq() {
    if ((status & FLAG_ZERO) == FLAG_ZERO) {
        oldpc = pc;
        pc += reladdr;
        if ((oldpc & 0xFF00) != (pc & 0xFF00)) clockticks6502 += 2; //check if jump crossed a page boundary
            else clockticks6502++;
    }
}

static void bit() {
    value = getvalue();
    result = (uint16_t)a & value;
   
    zerocalc(result);
    status = (status & 0x3F) | (uint8_t)(value & 0xC0);
}

static void bmi() {
    if ((status & FLAG_SIGN) == FLAG_SIGN) {
        oldpc = pc;
        pc += reladdr;
        if ((oldpc & 0xFF00) != (pc & 0xFF00)) clockticks6502 += 2; //check if jump crossed a page boundary
            else clockticks6502++;
    }
}

static void bne() {
    if ((status & FLAG_ZERO) == 0) {
        oldpc = pc;
        pc += reladdr;
        if ((oldpc & 0xFF00) != (pc & 0xFF00)) clockticks6502 += 2; //check if jump crossed a page boundary
            else clockticks6502++;
    }
}

static void bpl() {
    if ((status & FLAG_SIGN) == 0) {
        oldpc = pc;
        pc += reladdr;
        if ((oldpc & 0xFF00) != (pc & 0xFF00)) clockticks6502 += 2; //check if jump crossed a page boundary
            else clockticks6502++;
    }
}

static void brk_() {
    pc++;
    push16(pc); //push next instruction address onto stack
    push8(status | FLAG_BREAK); //push CPU status to stack
    setinterrupt(); //set interrupt flag
    pc = (uint16_t)read6502(0xFFFE) | ((uint16_t)read6502(0xFFFF) << 8);
}

static void bvc() {
    if ((status & FLAG_OVERFLOW) == 0) {
        oldpc = pc;
        pc += reladdr;
        if ((oldpc & 0xFF00) != (pc & 0xFF00)) clockticks6502 += 2; //check if jump crossed a page boundary
            else clockticks6502++;
    }
}

static void bvs() {
    if ((status & FLAG_OVERFLOW) == FLAG_OVERFLOW) {
        oldpc = pc;
        pc += reladdr;
        if ((oldpc & 0xFF00) != (pc & 0xFF00)) clockticks6502 += 2; //check if jump crossed a page boundary
            else clockticks6502++;
    }
}

static void clc() {
    clearcarry();
}

static void cld() {
    cleardecimal();
}

static void cli() {
    clearinterrupt();
}

static void clv() {
    clearoverflow();
}

static void cmp() {
    penaltyop = 1;
    value = getvalue();
    result = (uint16_t)a - value;
   
    if (a >= (uint8_t)(value & 0x00FF)) setcarry();
        else clearcarry();
    if (a == (uint8_t)(value & 0x00FF)) setzero();
        else clearzero();
    signcalc(result);
}

static void cpx() {
    value = getvalue();
    result = (uint16_t)x - value;
   
    if (x >= (uint8_t)(value & 0x00FF)) setcarry();
        else clearcarry();
    if (x == (uint8_t)(value & 0x00FF)) setzero();
        else clearzero();
    signcalc(result);
}

static void cpy() {
    value = getvalue();
    result = (uint16_t)y - value;
   
    if (y >= (uint8_t)(value & 0x00FF)) setcarry();
        else clearcarry();
    if (y == (uint8_t)(value & 0x00FF)) setzero();
        else clearzero();
    signcalc(result);
}

static void dec() {
    value = getvalue();
    result = value - 1;
   
    zerocalc(result);
    signcalc(result);
   
    putvalue(result);
}

static void dex() {
    x--;
   
    zerocalc(x);
    signcalc(x);
}

static void dey() {
    y--;
   
    zerocalc(y);
    signcalc(y);
}

static void eor() {
    penaltyop = 1;
    value = getvalue();
    result = (uint16_t)a ^ value;
   
    zerocalc(result);
    signcalc(result);
   
    saveaccum(result);
}

static void inc() {
    value = getvalue();
    result = value + 1;
   
    zerocalc(result);
    signcalc(result);
   
    putvalue(result);
}

static void inx() {
    x++;
   
    zerocalc(x);
    signcalc(x);
}

static void iny() {
    y++;
   
    zerocalc(y);
    signcalc(y);
}

static void jmp() {
    pc = ea;
}

static void jsr() {
    push16(pc - 1);
    pc = ea;
}

static void lda() {
    penaltyop = 1;
    value = getvalue();
    a = (uint8_t)(value & 0x00FF);
   
    zerocalc(a);
    signcalc(a);
}

static void ldx() {
    penaltyop = 1;
    value = getvalue();
    x = (uint8_t)(value & 0x00FF);
   
    zerocalc(x);
    signcalc(x);
}

static void ldy() {
    penaltyop = 1;
    value = getvalue();
    y = (uint8_t)(value & 0x00FF);
   
    zerocalc(y);
    signcalc(y);
}

static void lsr() {
    value = getvalue();
    result = value >> 1;
   
    if (value & 1) setcarry();
        else clearcarry();
    zerocalc(result);
    signcalc(result);
   
    putvalue(result);
}

static void nop() {
    switch (opcode) {
        case 0x1C:
        case 0x3C:
        case 0x5C:
        case 0x7C:
        case 0xDC:
        case 0xFC:
            penaltyop = 1;
            break;
    }
}

static void ora() {
    penaltyop = 1;
    value = getvalue();
    result = (uint16_t)a | value;
   
    zerocalc(result);
    signcalc(result);
   
    saveaccum(result);
}

static void pha() {
    push8(a);
}

static void php() {
    push8(status | FLAG_BREAK);
}

static void pla() {
    a = pull8();
   
    zerocalc(a);
    signcalc(a);
}

static void plp() {
    status = pull8() | FLAG_CONSTANT;
}

static void rol() {
    value = getvalue();
    result = (value << 1) | (status & FLAG_CARRY);
   
    carrycalc(result);
    zerocalc(result);
    signcalc(result);
   
    putvalue(result);
}

static void ror() {
    value = getvalue();
    result = (value >> 1) | ((status & FLAG_CARRY) << 7);
   
    if (value & 1) setcarry();
        else clearcarry();
    zerocalc(result);
    signcalc(result);
   
    putvalue(result);
}

static void rti() {
    status = pull8();
    value = pull16();
    pc = value;
}

static void rts() {
    value = pull16();
    pc = value + 1;
}

static void sbc() {
    penaltyop = 1;
    value = getvalue() ^ 0x00FF;
    result = (uint16_t)a + value + (uint16_t)(status & FLAG_CARRY);
   
    carrycalc(result);
    zerocalc(result);
    overflowcalc(result, a, value);
    signcalc(result);

    #ifndef NES_CPU
    if (status & FLAG_DECIMAL) {
        clearcarry();
        
        a -= 0x66;
        if ((a & 0x0F) > 0x09) {
            a += 0x06;
        }
        if ((a & 0xF0) > 0x90) {
            a += 0x60;
            setcarry();
        }
        
        clockticks6502++;
    }
    #endif
   
    saveaccum(result);
}

static void sec() {
    setcarry();
}

static void sed() {
    setdecimal();
}

static void sei() {
    setinterrupt();
}

static void sta() {
    putvalue(a);
}

static void stx() {
    putvalue(x);
}

static void sty() {
    putvalue(y);
}

static void tax() {
    x = a;
   
    zerocalc(x);
    signcalc(x);
}

static void tay() {
    y = a;
   
    zerocalc(y);
    signcalc(y);
}

static void tsx() {
    x = sp;
   
    zerocalc(x);
    signcalc(x);
}

static void txa() {
    a = x;
   
    zerocalc(a);
    signcalc(a);
}

static void txs() {
    sp = x;
}

static void tya() {
    a = y;
   
    zerocalc(a);
    signcalc(a);
}

//undocumented instructions
#ifdef UNDOCUMENTED
    static void lax() {
        lda();
        ldx();
    }

    static void sax() {
        sta();
        stx();
        putvalue(a & x);
        if (penaltyop && penaltyaddr) clockticks6502--;
    }

    static void dcp() {
        dec();
        cmp();
        if (penaltyop && penaltyaddr) clockticks6502--;
    }

    static void isb() {
        inc();
        sbc();
        if (penaltyop && penaltyaddr) clockticks6502--;
    }

    static void slo() {
        asl();
        ora();
        if (penaltyop && penaltyaddr) clockticks6502--;
    }

    static void rla() {
        rol();
        and();
        if (penaltyop && penaltyaddr) clockticks6502--;
    }

    static void sre() {
        lsr();
        eor();
        if (penaltyop && penaltyaddr) clockticks6502--;
    }

    static void rra() {
        ror();
        adc();
        if (penaltyop && penaltyaddr) clockticks6502--;
    }
#else
    #define lax nop
    #define sax nop
    #define dcp nop
    #define isb nop
    #define slo nop
    #define rla nop
    #define sre nop
    #define rra nop
#endif
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
int main(int argc, char *argv[]){
    if ((argc >= 2)&&((access(argv[1], F_OK) == 0))){
        FILE *f = fopen(argv[1], "rb") ;
        fread(MEM, 1, 0x10000, f) ;
        fclose(f) ;
    }
    else {
        printf("Usage: fake6502 BIN_FILE\n") ;
        exit(0) ;
    }

    reset6502() ;
    while(1){
        printf("%8ld  PC:0x%04X INST:0x%02X SP:0x%02X STATUS:0x%02X ACC:0x%02X X:0x%02X Y:0x%02X EA:0x%04X RAM[EA]:0x%02X\n", 
            instructions, pc, opcode, sp, status, a, x, y, ea, MEM[ea]) ;
        step6502() ;
    }
}

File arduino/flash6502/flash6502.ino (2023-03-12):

// Some globals...
unsigned long INST_CNT = 0 ;
uint8_t STEP_CNT = 0 ;
bool QUIET = true ;

// Push buttons for interrupts and stepping 
#define NMI   A5
#define IRQ   A4

// Some useful instruction opcodes and other defines
#define INST_RST1         0x2F
#define INST_RST2         0x3F
#define INST_NOP          0xEA
#define INST_IRQ          0xFF
#define INST_NMI          0xFB
#define MAX_STEP          64

#include "DATA.h"
#include "VECTORS.h"
void halt6502() ;
#include "IO.h"
#include "CTRL.h"
#include "PROG.h"
#include "TEST.h"

// Debug and optimization stuff
#define ENABLE_INTERRUPTS       0       
#define DEBOUNCE_INTERRUPTS     0
#define ENABLE_MONITORING       0
#define ENABLE_TRAP_DETECTION   0
#define ENABLE_VERBOSITY        1

#if ENABLE_MONITORING
   // We use these buttons also to enable monitoring and to do stepping. 
  #define STEP  NMI 
  #define MON   IRQ 
  #include "MONITOR.h"
#endif

#if ENABLE_INTERRUPTS
  #include "BUTTON.h"
  BUTTON NMI_BUTTON(NMI), IRQ_BUTTON(IRQ) ;
#endif
  
DATA DATA ;              // 9, 8, 7, 6, 5, 4, 3, 2
VECTORS VECTORS ;
IO IO ;
CTRL CTRL(&DATA, &VECTORS, &IO) ;      // 12, 11, 10, A1
PROG *prog = nullptr ;

#if ENABLE_MONITORING
  MONITOR MONITOR(&DATA) ;
  // Some globals useful for debugging.
  bool DEBUG_MON = false ;
  bool DEBUG_STEP = false ;
#endif


void setup() {
  // Faster analog reads
  ADCSRA = (ADCSRA & 0b11111000) | 0b100 ;

  Serial.begin(115200) ;
  #define SERIAL_TIMEOUT 1000
  Serial.setTimeout(SERIAL_TIMEOUT) ;
  // Send null byte to indicate we have finished booting, in case a loader is present.
  Serial.write(0) ;
  Serial.println(F("Starting Flash6502")) ;  

  prog = detect_loader() ;

  #if ENABLE_MONITORING
    if (! digitalRead(MON)){
      Serial.println(F("IRQ/MON button held down, entering monitor mode.\n")) ;
      DEBUG_MON = true ;
    }
    if (! digitalRead(STEP)){
      Serial.println(F("NMI/STEP button held down, entering step mode.\n")) ;
      DEBUG_STEP = true ;
      DEBUG_MON = true ;
    }
  #endif
  
  reset6502(0) ;
}


PROG *detect_loader(){
  // Read the magic number that indicates our loader is present.
  byte magic[3] ;
  int nb = Serial.readBytes(magic, 3) ;
  if ((magic[0] == 0x65)&&(magic[1] == 0x02)){
    IO.set_loader() ;
    if (magic[2] == 0xFF){
      Serial.println(F("Loader detected, program will be requested from loader.")) ;
      return new PROG("@loader") ;
    }
    else {
      Serial.println(F("Loader detected, continuing with built-in test suite.")) ;
    }
  }
  else {
    Serial.println(F("No loader detected, continuing with built-in test suite.")) ;
  }

  QUIET = false ;
  return new PROG("TestSuite", test_suite, 14649, true, 0x0400, 0x38A7, 0x3899, 0x3699) ;
}


void reset6502(uint16_t force_start_addr){
  // Clear step counter and program counter
  CTRL.pulse(STEP_CLR) ;
  CTRL.pulse(PC_CLR) ;
  // Reset latches
  CTRL.pulse_sync() ;

  #if ENABLE_MONITORING
    MONITOR.sample() ;
    MONITOR.trace("INIT  ->") ;
  #endif
  
  // Initialize INST register to RST1
  insert_inst(INST_RST1, true) ;

  #if ENABLE_VERBOSITY
    Serial.print(F("- Loading program to RAM...")) ;
  #endif
  CTRL.pulse(STEP_CLR) ;
  CTRL.pulse(PC_CLR) ;
  // Load the program to RAM
  for (int data = prog->get_next_byte() ; data != -1 ; data = prog->get_next_byte()){
    DATA.write(data) ; 
    CTRL.PC_e_on() ;
    CTRL.pulse_with_sync(RAM_S) ;
    CTRL.PC_e_off() ;
    DATA.reset() ;
    CTRL.pulse_with_sync(PC_UP) ;
  }

  #if ENABLE_VERBOSITY
    Serial.println(F("done")) ;
    Serial.print(F("LOAD  -> ")) ;
    Serial.print(prog->len()) ;
    Serial.println(F(" program bytes loaded")) ;
    
    // Print program info
    prog->describe() ;
    Serial.println() ;
  #endif

  // Now that program is transfered, install vectors in controller
  VECTORS.set_reset(force_start_addr ? force_start_addr : prog->start_addr()) ;
  VECTORS.set_int(prog->int_addr()) ;
  VECTORS.set_nmi(prog->nmi_addr()) ;

  CTRL.pulse(STEP_CLR) ;
  insert_inst(INST_RST2, true) ;

  // We must place another instruction here because RST2 doesn't load the next instruction.
  insert_inst(INST_NOP, false) ;

  #if ENABLE_MONITORING
    MONITOR.sample() ;
    MONITOR.trace("RESET ->") ;
  #endif
  #if ENABLE_VERBOSITY
    Serial.println(F("---")) ;
  #endif
}


void insert_inst(uint8_t opcode, bool process){
  DATA.write(opcode) ;
  #if ENABLE_MONITORING
    MONITOR.set_inst(opcode) ;
  #endif
  CTRL.pulse_with_sync(INST_S) ;
  DATA.reset() ;

  if (process){
    process_inst(false) ; 
  }
}


inline void process_inst(bool grab_inst){
  bool prev_ctrl = false ; 
  while (1){    
    #if ENABLE_MONITORING
      MONITOR.process(grab_inst) ;
      if (STEP_CNT > 0){
        // This already happened for step 0 when we called STEP_CLR
        CTRL_pulse_async_fast() ; 
        CTRL_pulse_sync_fast() ;  
      }
    #else
      CTRL_pulse_async_fast() ; 
      CTRL_pulse_sync_fast() ;  
    #endif
  
    if (PINC & 0b100){ // A2, CTRL
      CTRL.process() ;
      prev_ctrl = true ;
    }
    else if (prev_ctrl){
      CTRL.clear_cache() ;
      DATA.reset() ;
      prev_ctrl = false ;
    }
  
    #if ENABLE_MONITORING
      if (DEBUG_MON){
        if (DEBUG_STEP){
          MONITOR.step() ;
        }
        else {
          MONITOR.trace() ;
        }
      }
    #endif
  
    if (PINC & 0b1000){ // A3, INST_done
      #if ENABLE_VERBOSITY
        #if ENABLE_MONITORING
          if (grab_inst){
            INST_CNT++ ;
          }
        #else
          INST_CNT++ ;
        #endif
      #endif
      // Reset step counter.
      CTRL_pulse_step_clr_fast() ;
      #if ENABLE_MONITORING
        STEP_CNT = 0 ;
      #endif
      return ;
    }
    #if ENABLE_MONITORING
      STEP_CNT++ ;
    #endif
  }
}
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

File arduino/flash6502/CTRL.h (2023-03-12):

#ifndef CTRL_H
#define CTRL_H


//#define CTRL  A2         // Activate controller for vectors and IO
#define CTRL_ADDR0 A2
#define CTRL_ADDR1 A3
#define CTRL_ADDR2 A6
#define CTRL_ADDR3 A7

#define CLK_ASYNC  0b00100
#define STEP_CLR   0b01000
#define RAM_S      0b10000
#define INST_S     0b10100
#define PC_UP      0b11000
#define PC_CLR     0b11100

 
#define CTRL_pulse_async_fast()     asm("sbi 0x05, 2\ncbi 0x05, 2\n") ;
#define CTRL_pulse_step_clr_fast()  asm("sbi 0x05, 3\ncbi 0x05, 3\n") ;
#define CTRL_pulse_sync_fast()      asm("cbi 0x08, 1\nsbi 0x08, 1\n") ;


// Pins 12, 11, 10: PORTB, bits 4, 3, 2
// Sync is A1: PORTC, bit 2
// PC_e is A0: PORTC, bit 1
// CTRL_src is 13: PORTB, bit 5
class CTRL {
  private:
    DATA *_data ;
    VECTORS *_vectors ;
    IO *_io ;
    uint8_t _cache ; 
  
  public:
    CTRL(DATA *data, VECTORS *vectors, IO *io){
      _data = data ;
      _vectors = vectors ;
      _io = io ; 
      _cache = 0 ;
      // Set pins to output  
      DDRB  |= 0b00011100 ;
      DDRC  |= 0b00000011 ;
      PORTC |= 0b00000011 ;
    }

    inline void clear_cache(){
      _cache = 0 ;
    }
    
    inline void pulse_sync(){
      // Set control bits (bits 4, 3, 2), which are already 0.
      PORTC &= 0b11111101 ;
      PORTC |= 0b00000010 ;
    }

    inline void pulse(uint8_t cmd){
      // Set control bits (bits 4, 3, 2), which are already 0.
      PORTB |= cmd ;
      // Clear control bits
      PORTB &= 0b11100011 ;            
    }
    
    inline void pulse_with_sync(uint8_t cmd){
      // Set control bits (bits 4, 3, 2), which are already 0.
      PORTB |= cmd ;
      pulse_sync() ;
      // Clear control bits
      PORTB &= 0b11100011 ;
      pulse_sync() ;
    }

    inline void PC_e_on(){
      PORTC &= 0b11111110 ;
    }

    inline void PC_e_off(){
      PORTC |= 0b00000001 ;
    }

    inline void CTRL_src_on(){
      PORTB |= 0b00100000 ;
    }

    inline void CTRL_src_off(){
      PORTB &= 0b11011111 ;
    }

    #define analogRead2Digital(apin)  (analogRead(apin) >= 512)
    inline void process(){
      if (! analogRead2Digital(CTRL_ADDR3)){  // RAM_e.read()
        CTRL_src_on() ;
        uint8_t addr = analogRead2Digital(CTRL_ADDR3) << 3 | analogRead2Digital(CTRL_ADDR2) << 2 | digitalRead(CTRL_ADDR1) << 1 | digitalRead(CTRL_ADDR0) ;  
        CTRL_src_off() ;
        // read from vectors or IO
        if (addr < 0xA){
          if (! _cache){
            _cache = _io->get_byte(addr) ;
          }
          _data->write(_cache) ;
        }
        else {
          _data->write(_vectors->get_byte(addr)) ;
        }
      }
      else {
        _cache = 0 ;
        _data->reset() ;     
      }
    
      if (! analogRead2Digital(CTRL_ADDR2)){  // RAM_s.read()
        // write to vectors or IO
        CTRL_src_on() ;
        uint8_t addr = analogRead2Digital(CTRL_ADDR3) << 3 | analogRead2Digital(CTRL_ADDR2) << 2 | digitalRead(CTRL_ADDR1) << 1 | digitalRead(CTRL_ADDR0) ;  
        CTRL_src_off() ;
        if (addr < 0xA){
          _io->set_byte(addr, _data->read()) ;
        }
        else {
          _vectors->set_byte(addr, _data->read()) ;
        }
      }
    }
} ;


#endif

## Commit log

2022-11-15 added circuit
2022-11-24 ok bug in counter
    [fake6502.c]
2022-11-26 Fix load signal for counter_updown
    [fake6502.c]
2022-12-05 flipped RAM_s logic like on chip
    [fake6502.c]
2022-12-15 ok, now time to do it for real on the board...
2022-12-18 interrupts ok now!
2022-12-20 interrupt ok
2022-12-21 - I bug - free CTRL ROMS 3-4-5 of all synchronous signals
    [fake6502.c]
2022-12-25 swap STEP_clr for INST_done in CU
    [fake6502.c]
2022-12-27 removed arduino #2
2022-12-29 switch to pc
2023-01-08 can't use strcpy
    [flash6502.cfg]
2023-01-09 fixed bug in asl zpg
    [flash6502.cfg]
2023-01-11 ok, fixed for now
    [fake6502.c]
2023-01-13 trace and stuff
2023-01-17 kicad schematic
    [ALU.kicad_sch, Address_High.kicad_sch, Address_Low.kicad_sch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]
2023-01-25 kicad update
    [CTRL45.kicad_sch, flash6502.kicad_sch]
2023-01-29 fixed interrupts
2023-02-26 ok, docs
    [CTRL12.kicad_sch, CTRL3.kicad_sch, CTRL45.kicad_sch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]
